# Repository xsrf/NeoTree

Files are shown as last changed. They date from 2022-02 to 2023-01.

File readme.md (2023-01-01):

# NeoTree

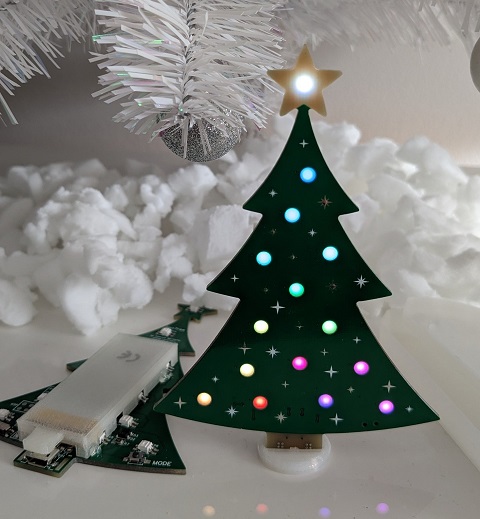
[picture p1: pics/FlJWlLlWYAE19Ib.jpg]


## Features
- Christmas-Tree style PCB
- 15 NeoPixel RGB LEDs (SK6812) shining through the PCB
- Powered by rechargeable LiPo Battery
- Charged via MicroUSB (2h full charge)
- Custom programming via MicroUSB
- Based on ATTiny85 microcontroller
- Mode/Animation selection via Button

A **short press** on the MODE button cycles the available modes. When you **hold down** the MODE button, the current animations slows down or changes its style each time the star flashes.
## Getting started (programming)

### Installing VSCode and PlatformIO
Install [VSCode](https://code.visualstudio.com/) and open the downloaded/cloned [project folder](https://github.com/xsrf/NeoTree/archive/refs/heads/master.zip) in VScode.
VSCode should ask you to install the PlatformIO extension - do so.
You may need to close VSCode and open the folder once again in VSCode for PlatformIO to recognize the project.
Open `src/main.c` and look for "Build", "Upload", "Home" buttons on the bottom bar of VSCode.

### Installing Zadig (Windows)
Download Zadig from [here](https://zadig.akeo.ie/) or [github releases](https://github.com/pbatard/libwdi/releases). 
Zadig is used to install the required USB driver. See the [documentation](https://github.com/pbatard/libwdi/wiki/Zadig) for more details and screenshots.
Assign the `libusb-win32` driver (not `winusb`).

To do so, the NeoTree needs to be pre-flashed with the USB bootloader (see *usb-bootloader* subfolder), turned off, connected via MicroUSB cable and then turned on. It should appear in Zadig. Select "Options - List All Devices" if it doesn't. Select `libusb-win32` and click install.

### Compile and upload code
Open the project folder in VSCode and open `src/main.c`. Make sure to select `env:usb` in the bottom bar of VSCode as PlatformIO environment.
Connect the NeoTree via USB but keep it turned off.
Then hit upload ("->" Button) and follow the console output.
When it says `Please plug in the device (will time out in 60 seconds) ...` turn on the NeoTree. It should immediately upload the new code.

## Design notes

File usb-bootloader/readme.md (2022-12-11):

# Burn USB Bootloader and Fuses
[Micronucleus](https://github.com/micronucleus/micronucleus) is a bootloader designed for AVR ATtiny microcontrollers with a minimal usb interface.
This needs to be flashed once via ICSP. After that, the NeoTree can be flashed with new firmware via USB.
You'll need an ICSP programmer for that.
```
avrdude.exe -c usbasp -B4 -p t85 -v -U flash:w:t85_usbdemo.hex
avrdude.exe -c usbasp -B4 -p t85 -v -U lfuse:w:0xe1:m -U hfuse:w:0xde:m -U efuse:w:0xfe:m
```
See [here](https://eleccelerator.com/fusecalc/fusecalc.php?chip=attiny85&LOW=E1&HIGH=DE&EXTENDED=FE) for fuse description.

## Files
| File | Description |
|---|---|
| backup_attiny85.bat | Reads and backups the contents of the flash |
| flash_attiny85_usbdemo.bat | Flash USB bootloader and Demo program (recommended) |
| flash_attiny85_usbonly.bat | Flash USB bootloader |
| t85_default.hex | Standard micronucelos bootloader |
| t85_fastexit.hex | Micronucelos bootloader which only waits few milliseconds |
| t85_usbdemo.hex | Fastexit micronucelos bootloader and NeoPixel Demo |

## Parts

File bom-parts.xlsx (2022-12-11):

Part | Count | Price/Part | Price
PCB | 1 | 3.00 € | 3.00 €
SK2301AA1SHB | 2 | 0.02 € | 0.05 €
R0805 (4K7) | 5 | 0.01 € | 0.03 €
ATTINY85-20SH | 1 | 2.50 € | 2.50 €
BZT52C3V6 | 2 | 0.01 € | 0.02 €
B5819WS | 2 | 0.01 € | 0.02 €
R0805 (47R) | 2 | 0.01 € | 0.02 €
SK6812MINI | 15 | 0.12 € | 1.80 €
C0805 (100n) | 3 | 0.01 € | 0.03 €
USB_MICRO_SMD | 1 | 0.03 € | 0.03 €
MSK12C02 (Switch) | 1 | 0.02 € | 0.02 €
K2-1107ST-A4SW-06 (Button) | 1 | 0.02 € | 0.02 €
TP4056 | 1 | 0.03 € | 0.03 €
LED-0805 (red/charging) | 1 | 0.01 € | 0.01 €
Battery (402050) | 1 | 3.00 € | 3.00 €

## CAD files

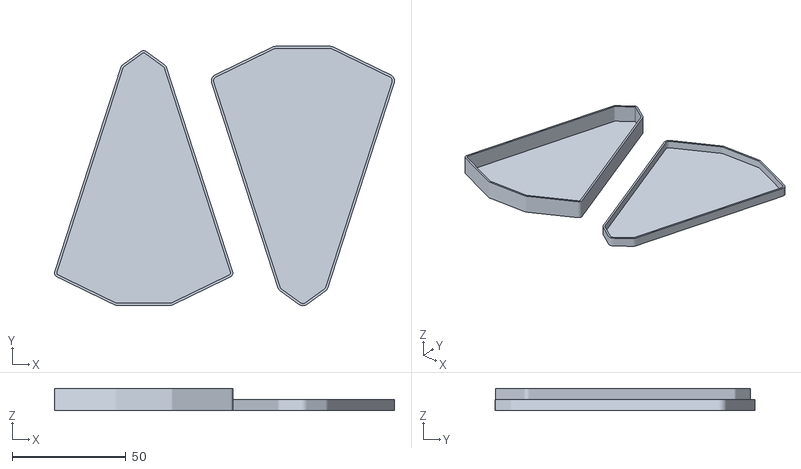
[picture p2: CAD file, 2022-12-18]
3d-prints/tree-case.stl
149.5 x 114.1 x 9.80

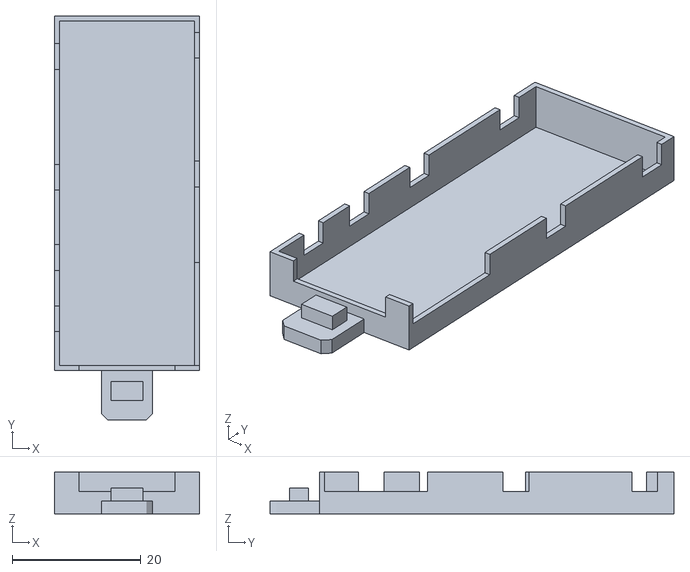
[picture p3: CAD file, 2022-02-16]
3d-prints/neotree-battery-case.stl
22.6 x 62.8 x 6.50

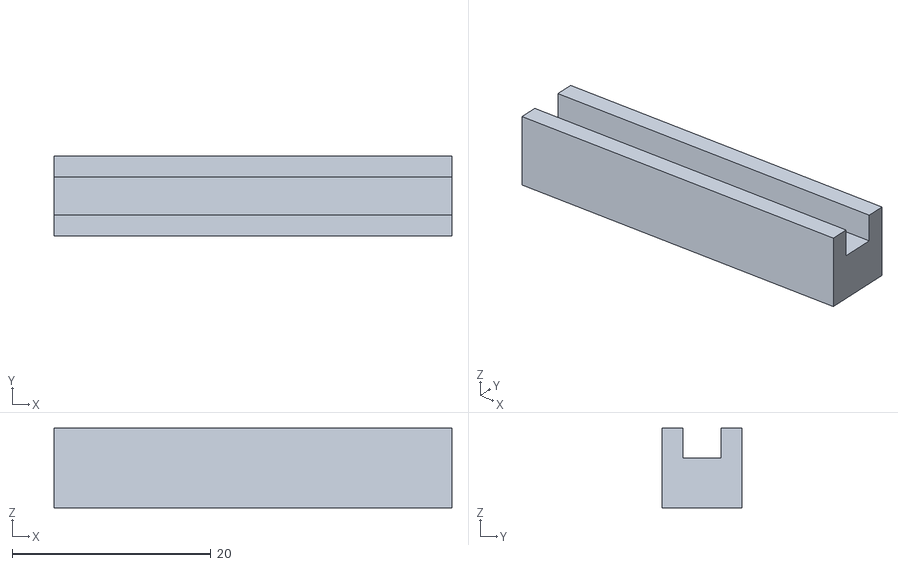
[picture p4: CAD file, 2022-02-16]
3d-prints/neotree-led-stamp.stl
40.0 x 8.00 x 8.00

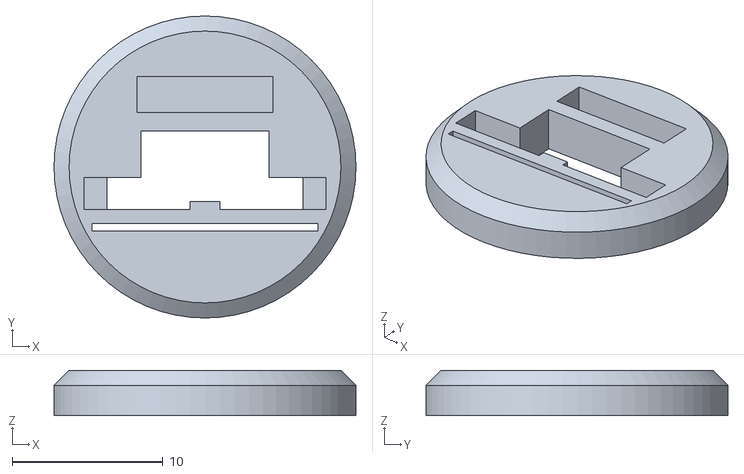
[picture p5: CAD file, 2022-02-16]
3d-prints/neotree-foot-v3.stl
20.0 x 20.0 x 3.00

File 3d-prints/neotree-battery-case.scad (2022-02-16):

/* 
    Print: 
    0.25 layer height
    0.42 extrusion width
*/

$bw = 21;
$bl = 53.5;
$ch = 6; // case height (4mm battery + LEDs)
$w = 0.8; // case wall width
$f = 0.5; // case floor thickness


translate([0,19,6]) rotate([0,180,0]) scale([0.254,0.254,0.254]) %import("OBJ_NeoTree PCB.stl");

difference() {
    battery_case();
    battery_case_cutouts();
}

translate([0,-($bl/2+$w),0]) case_foot();

module battery_case() {
    translate([0,0,$ch/2-$f/2]) difference() {
        cube([$bw+2*$w, $bl+2*$w, $ch+$f],center=true);
        translate([0,0,$f]) cube([$bw, $bl, $ch+$f],center=true);
    }
}

module battery_case_cutouts() {
    translate([$bw/2,$bl/2-3.75,$ch]) cube([4,4,$ch],center=true);
    translate([$bw/2,3,$ch]) cube([4,4,$ch],center=true);
    translate([$bw/2,-$bl/2+8,$ch]) cube([4,16,$ch],center=true);

    translate([-$bw/2,$bl/2-5.5,$ch]) cube([4,4,$ch],center=true);
    translate([-$bw/2,2.5,$ch]) cube([4,4,$ch],center=true);
    translate([-$bw/2,-10,$ch]) cube([4,4,$ch],center=true);
    translate([-$bw/2,-19.5,$ch]) cube([4,4,$ch],center=true);

    translate([0,-$bl/2,$ch]) cube([15,4,$ch],center=true);

}

module case_foot() {
    $l = 7.7;
    hull() {
        translate([-4,-$l+1,-$f]) cube([8,$l-1,2]);
        translate([-3,-$l,-$f]) cube([6,$l,2]);
    }
    translate([-2.5,-$l+3,-$f]) cube([5,3,4]);
}

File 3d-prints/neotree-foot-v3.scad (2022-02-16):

$usbh = 4.7;
$pcbt = 1.6;
difference() {
    translate([0,1.5,0]) hull() {
        cylinder(r=10,h=2,$fn=64);
        cylinder(r=9,h=3,$fn=64);
    }
    //translate([0,0,10/2+0.25])cube([16,$pcbt,10],center=true);
    cube([16,$pcbt,20],center=true);
    #translate([0,$usbh/2-$pcbt/2])cube([8.5,$usbh,20],center=true);
    translate([0,-0.5,0]) difference() {
        cube([16,$pcbt,20],center=true);
        cube([2,2,20],center=true);
    }
    
    // Flex split
    translate([0,-2.5,0]) cube([15,0.5,20],center=true);
    
    // Battery Case Stand Cutout
    translate([0,$pcbt/2+5.5,20/2+0.25]) cube([9,2.4,20],center=true);
}

translate([0,0,0.25/2]) difference() {
    cube([16,3,0.25],center=true);
    cube([13,3,5],center=true);
}

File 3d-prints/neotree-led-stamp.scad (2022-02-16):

difference() {
    cube([40,8,8],center=true);
    translate([0,0,5]) cube([51,3.8,8],center=true);
}

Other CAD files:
3d-prints/tree-case.scad
pcb-masks/stars.scad
pcb-masks/tree.scad

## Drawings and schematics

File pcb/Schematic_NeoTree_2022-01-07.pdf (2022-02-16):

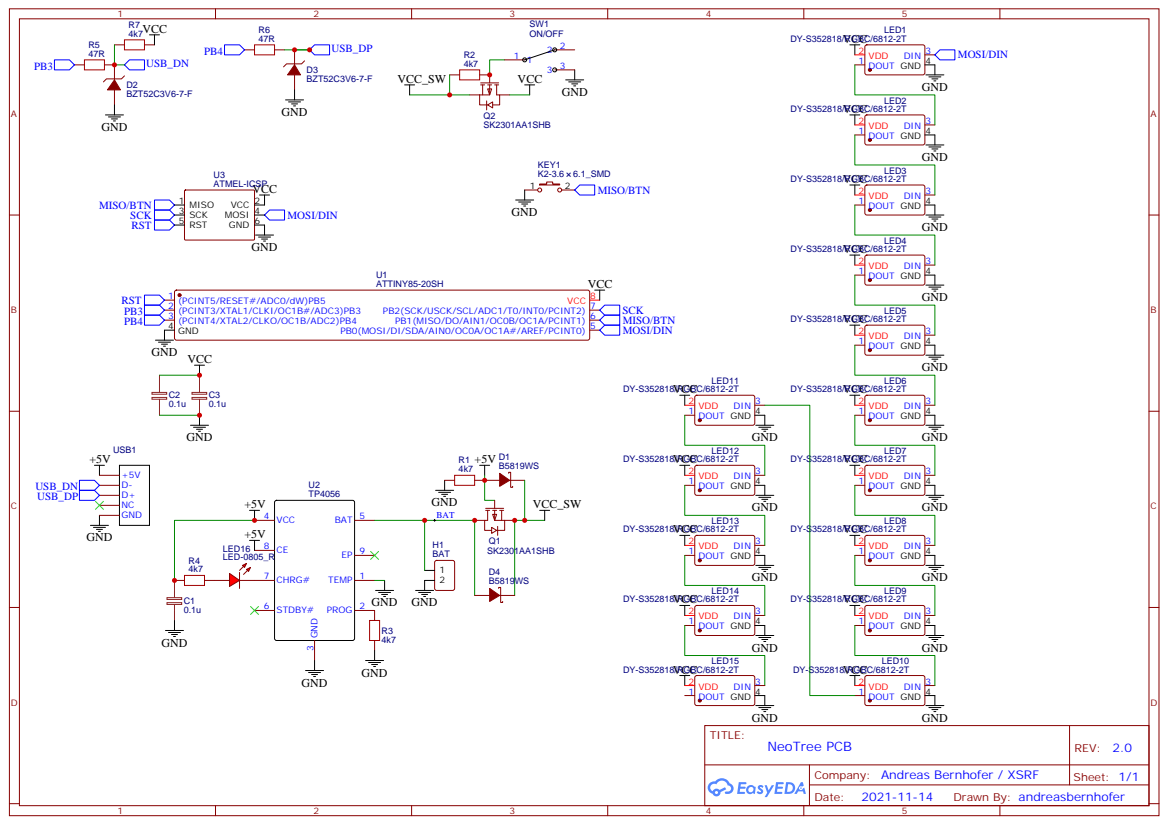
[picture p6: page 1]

PB0(MOSI/DI/SDA/AIN0/OC0A/OC1A#/AREF/PCINT0) 5

Company: Andreas Bernhofer / XSRF

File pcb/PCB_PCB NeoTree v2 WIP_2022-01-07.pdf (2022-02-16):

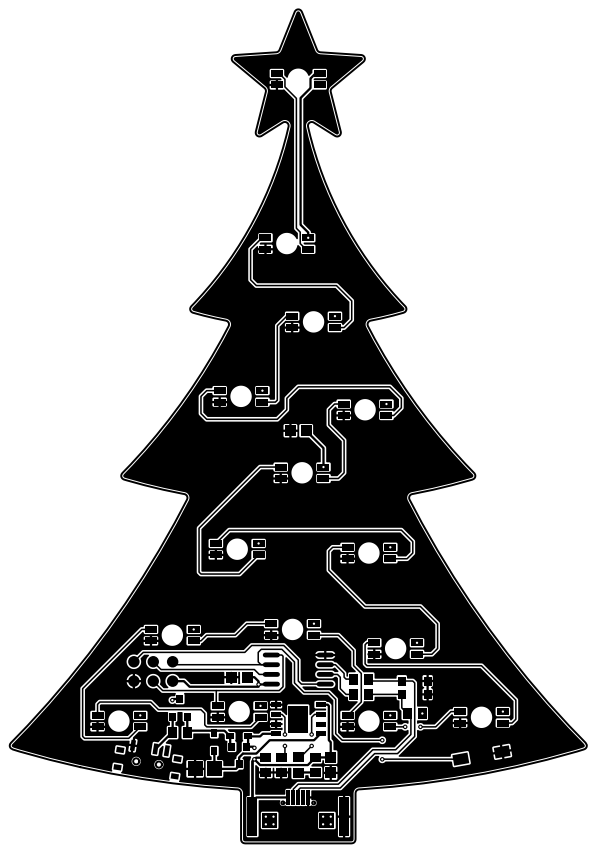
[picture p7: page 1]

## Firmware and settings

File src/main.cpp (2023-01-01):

/*
  NeoTree
  -------

  Want to program via USB? Make sure to select "env:usb" as PlatformIO environment on the bottom!

*/


#include <Arduino.h>
#include <Adafruit_NeoPixel.h>


const uint8_t LED_PIN = PB0; // works!
const uint8_t BTN = PB1; // BTN to GND
const uint8_t NUM_LEDS = 15;
const uint8_t LONG_PRESS_CNT = 20;

//                                    0  1  2  3  4  5  6  7  8  9 10 11 12 13 14
const uint8_t LED_ROWSD[NUM_LEDS] = { 2, 3, 3, 2, 1, 0, 1, 2, 3, 3, 3, 4, 4, 5, 6 }; // Diagonal rows index
const uint8_t LED_ROWSH[NUM_LEDS] = { 0, 0, 1, 1, 0, 0, 1, 2, 2, 3, 4, 4, 5, 6, 7 }; // Horizontal rows index
const uint8_t LED_POSX[NUM_LEDS] = {  }; // X-Coordinate of LED, centered around 128 - TODO
const uint8_t LED_POSY[NUM_LEDS] = {  }; // Y-Coordinate of LED, 0 bottom 255 top - TODO

unsigned long BTN_PRESS_CNT,GLOBAL_CNT;
byte MODE,SUBMODE = 0;


//const uint8_t LED_PIN = PB1; // Builtin-LED; red is yellow?!
//const uint8_t LED_PIN = PB2; // works!
//const uint8_t LED_PIN = PB3; // works! USB D-; LED white at start
//const uint8_t LED_PIN = PB4; // works! USB D+; LED white at start
//const uint8_t LED_PIN = PB5; // DOES NOT WORK!

Adafruit_NeoPixel strip = Adafruit_NeoPixel(NUM_LEDS, LED_PIN, NEO_GRB + NEO_KHZ800);

uint8_t getRandomPixel();
uint16_t getRandomInt(uint16_t max);
uint32_t fadeBlack(uint32_t color);

/*
    ### ANIMATIONS ###
*/

void ani_rainbow(uint8_t mul = 1) {
  static float offset;
  offset = offset + 4.0/(SUBMODE+1);
  uint8_t offs = round(offset);
  for(uint8_t i=0; i<NUM_LEDS; i++) strip.setPixelColor(i, strip.ColorHSV((offs+mul*i*(256/NUM_LEDS))<<8,255,255)); 
  strip.setPixelColor(NUM_LEDS-1, strip.Color(255,255,255));
}

void ani_rainbow_white_h(uint8_t mul = 1) {
  static float offset;
  offset = offset + 4.0/(SUBMODE+1);
  uint8_t offs = round(offset);
  for(uint8_t i=0; i<NUM_LEDS; i++) {
    strip.setPixelColor(i, strip.ColorHSV((offs+mul*i*(256/NUM_LEDS))<<8,255,255));
    if(LED_ROWSH[i]%2 == 1 ) strip.setPixelColor(i, strip.Color(175,175,175));
  }
  strip.setPixelColor(NUM_LEDS-1, strip.Color(255,255,255));
}

void ani_rainbow_white_d(uint8_t mul = 1) {
  static float offset;
  offset = offset + 4.0/(SUBMODE+1);
  uint8_t offs = round(offset);
  for(uint8_t i=0; i<NUM_LEDS; i++) {
    strip.setPixelColor(i, strip.ColorHSV((offs+mul*i*(256/NUM_LEDS))<<8,255,255));
    if(LED_ROWSD[i]%2 == 0 ) strip.setPixelColor(i, strip.Color(175,175,175));
  }
  strip.setPixelColor(NUM_LEDS-1, strip.Color(255,255,255));
}


void ani_solid_color() {
  for(uint8_t i=0; i<NUM_LEDS; i++) strip.setPixelColor(i, strip.ColorHSV(((SUBMODE*20)%256)<<8,255,255));
  strip.setPixelColor(NUM_LEDS-1, strip.Color(255,255,255));
}

void white_sparkles() {
  for(uint8_t i=0; i<NUM_LEDS; i++) strip.setPixelColor(i, strip.Color(0, 0, 0));
  if((GLOBAL_CNT % (2 + SUBMODE)) == 0) {
    strip.setPixelColor( getRandomPixel() , strip.Color(255, 255, 255));
  }
  strip.setPixelColor(NUM_LEDS-1, strip.Color(255, 255, 255));
}

void white_sparkles_rand() {
  for(uint8_t i=0; i<NUM_LEDS; i++) {
    if(getRandomInt(SUBMODE+3)==0 && strip.getPixelColor(i)== strip.Color(0, 0, 0) ) {
      strip.setPixelColor(i, strip.Color(255, 255, 255));
    } else {
      strip.setPixelColor(i, strip.Color(0, 0, 0));
    }
  }
  strip.setPixelColor(NUM_LEDS-1, strip.Color(255, 255, 255));
}

void white_sparkles_fade() {
  for(uint8_t i=0; i<NUM_LEDS; i++) {
    if(getRandomInt(SUBMODE+3)==0 && strip.getPixelColor(i)== strip.Color(0, 0, 0) ) {
      strip.setPixelColor(i, strip.Color(255, 255, 255));
    } else {
      strip.setPixelColor(i, fadeBlack(strip.getPixelColor(i)));      
    }
  }
  strip.setPixelColor(NUM_LEDS-1, strip.Color(255, 255, 255));
}

void random_colors() {
  if((GLOBAL_CNT % (2 + SUBMODE)) == 0) {
    strip.setPixelColor( getRandomPixel() , strip.ColorHSV(getRandomInt(255)<<8,255,255) );
  }
  strip.setPixelColor(NUM_LEDS-1, strip.Color(255, 255, 255));
}

/*
    ### OTHER STUFF ###
*/

uint8_t getRandomPixel() {
  return floor( rand()/(RAND_MAX/(NUM_LEDS-1)) );
}

uint16_t getRandomInt(uint16_t max) {
  return floor( rand()/(RAND_MAX/(max+1)) );
}

uint32_t fadeBlack(uint32_t color) {
  return ( color >> 1) & 0x7F7F7F7F;
}

long readVcc() {
  // Read 1.1V reference against AVcc
  // set the reference to Vcc and the measurement to the internal 1.1V reference
  #if defined(__AVR_ATmega32U4__) || defined(__AVR_ATmega1280__) || defined(__AVR_ATmega2560__)
    ADMUX = _BV(REFS0) | _BV(MUX4) | _BV(MUX3) | _BV(MUX2) | _BV(MUX1);
  #elif defined (__AVR_ATtiny24__) || defined(__AVR_ATtiny44__) || defined(__AVR_ATtiny84__)
    ADMUX = _BV(MUX5) | _BV(MUX0);
  #elif defined (__AVR_ATtiny25__) || defined(__AVR_ATtiny45__) || defined(__AVR_ATtiny85__)
    ADMUX = _BV(MUX3) | _BV(MUX2);
  #else
    ADMUX = _BV(REFS0) | _BV(MUX3) | _BV(MUX2) | _BV(MUX1);
  #endif   
  delay(2); // Wait for Vref to settle
  ADCSRA |= _BV(ADSC); // Start conversion
  while (bit_is_set(ADCSRA,ADSC)); // measuring 
  uint8_t low  = ADCL; // must read ADCL first - it then locks ADCH  
  uint8_t high = ADCH; // unlocks both 
  long result = (high<<8) | low; 
  result = 1125300L / result; // Calculate Vcc (in mV); 1125300 = 1.1*1023*1000
  return result; // Vcc in millivolts
}

void showChargingLevel() {
  long vcc = readVcc(); // Vcc in millivolts
  if(vcc >= 3200) {
    vcc = vcc - 3200; // 3200-4200 -> 0-1000
    vcc = vcc*NUM_LEDS; 
    vcc = vcc/1000; // 0-15
    if(vcc > NUM_LEDS) vcc = NUM_LEDS; // clamp to NUM_LEDS
  } else {
    vcc = 0;
  }
  for(uint8_t i=0; i<NUM_LEDS; i++) strip.setPixelColor(i, strip.Color(50, 0, 0)); // all red
  for(uint8_t i=0; i<vcc; i++) strip.setPixelColor(i, strip.Color(0, 50, 0)); // vcc amount green leds
  strip.show(); 
}

void btnCheck() {
  // Check Button press
  if(digitalRead(BTN) == 0) {
    strip.setPixelColor(NUM_LEDS-1, strip.Color(10, 10, 10));
    BTN_PRESS_CNT++;
    if(BTN_PRESS_CNT%LONG_PRESS_CNT == 0) {
      // Long press action every ~second
      SUBMODE++;
      strip.setPixelColor(NUM_LEDS-1, strip.Color(255, 255, 255));
    }
  } else {
    if(BTN_PRESS_CNT > 1 && BTN_PRESS_CNT < LONG_PRESS_CNT) {
      // Single press action
      MODE++;
      SUBMODE = 0; // reset Sub-Mode when changing to next mode/animation
      GLOBAL_CNT = 0;
      strip.setPixelColor(NUM_LEDS-1, strip.Color(255, 255, 255));
    }
    BTN_PRESS_CNT = 0;
  }
}

void setup() {
  // put your setup code here, to run once:
  cli(); // Disable interrupts
  //CLKPR = (1<<CLKPCE); // Prescaler enable
  //CLKPR = 0x00; // Clock division factor 8 (0011)
  sei(); // Enable interrupts
  //delay(1e3);
  pinMode(BTN,INPUT_PULLUP);
  strip.begin();
  strip.setBrightness(16);
  if(digitalRead(BTN) == 0) strip.setBrightness(32);
  strip.show(); // Initialize all pixels to 'off'
  for(uint8_t i=0; i<NUM_LEDS; i++) strip.setPixelColor(i, strip.Color(30, 30, 30)); strip.show(); delay(500);  // all white - pixel test
  for(uint8_t i=0; i<NUM_LEDS; i++) strip.setPixelColor(i, strip.Color(0, 0, 0)); strip.show(); delay(50); // all off
  showChargingLevel();
  delay(1000);
}


void loop() {
  switch (MODE) {
    case __COUNTER__: ani_rainbow(); break;
    case __COUNTER__: ani_rainbow_white_h(); break;
    case __COUNTER__: ani_rainbow_white_d(); break;
    case __COUNTER__: ani_rainbow(0); break;
    case __COUNTER__: ani_rainbow_white_h(0); break;
    case __COUNTER__: ani_rainbow_white_d(0); break;
    case __COUNTER__: ani_rainbow(7); break;
    case __COUNTER__: ani_rainbow_white_h(7); break;
    case __COUNTER__: ani_rainbow_white_d(7); break;
    case __COUNTER__: ani_solid_color(); break;
    case __COUNTER__: white_sparkles(); break;
    case __COUNTER__: white_sparkles_fade(); break;
    case __COUNTER__: random_colors(); break;
    default: MODE = 0; break;
  }  
  GLOBAL_CNT++; // global frame count, used for some animations
  btnCheck();
  strip.show(); 
  delay(33); // ~30fps
}

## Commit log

2022-12-11 add bom/cost estimates
    [bom-parts.xlsx]
2022-12-11 mode button description
2022-12-18 add case
    [tree-case.scad, tree-case.stl]
